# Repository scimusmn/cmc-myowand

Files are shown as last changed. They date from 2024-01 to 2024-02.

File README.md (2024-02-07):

# cmc-myowand

A myoelectric sensor demonstrator, converting muscular electrical impulses into music.

## overview

There are two main subfolders here: `electronics` contains the schematics and board layouts, as well as some information on how they were designed. `code` contains two things:

 * `cinci-biomed-myo`: the Arduino sketch that processes the amplified myoelectric signals and outputs them to the computer over serial
 * `myowand-audio`: the JavaScript code to receive the Arduino's messages and conver them into musical tones.

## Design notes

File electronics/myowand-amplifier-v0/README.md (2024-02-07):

# myowand-amplifier-v0

A prototype version of the MyoWand board. **I CANNOT EMPHASIZE ENOUGH THAT THIS BOARD IS A PROTOTYPE!** It omits several features that should be included in the final design. This board is essentially a pared-down version of the [ModularEEG amplifier board](https://openeeg.sourceforge.net/doc/modeeg/modeeg.html).

The TRS jacks connect to external [Olimex active electrodes](https://www.olimex.com/Products/EEG/Electrodes/EEG-AE/open-source-hardware) which seem to give much better signals than ordinary electrodes, especially without electrolyte solution.

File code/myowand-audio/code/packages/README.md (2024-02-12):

# myowand-audio/code/packages

  * `server`: a NodeJS server that takes serial data from the Arduino and re-transmits it to the browser via websockets.
  * `browser`: a vanilla-js application that both plots incoming websocket data and converts it to sound.

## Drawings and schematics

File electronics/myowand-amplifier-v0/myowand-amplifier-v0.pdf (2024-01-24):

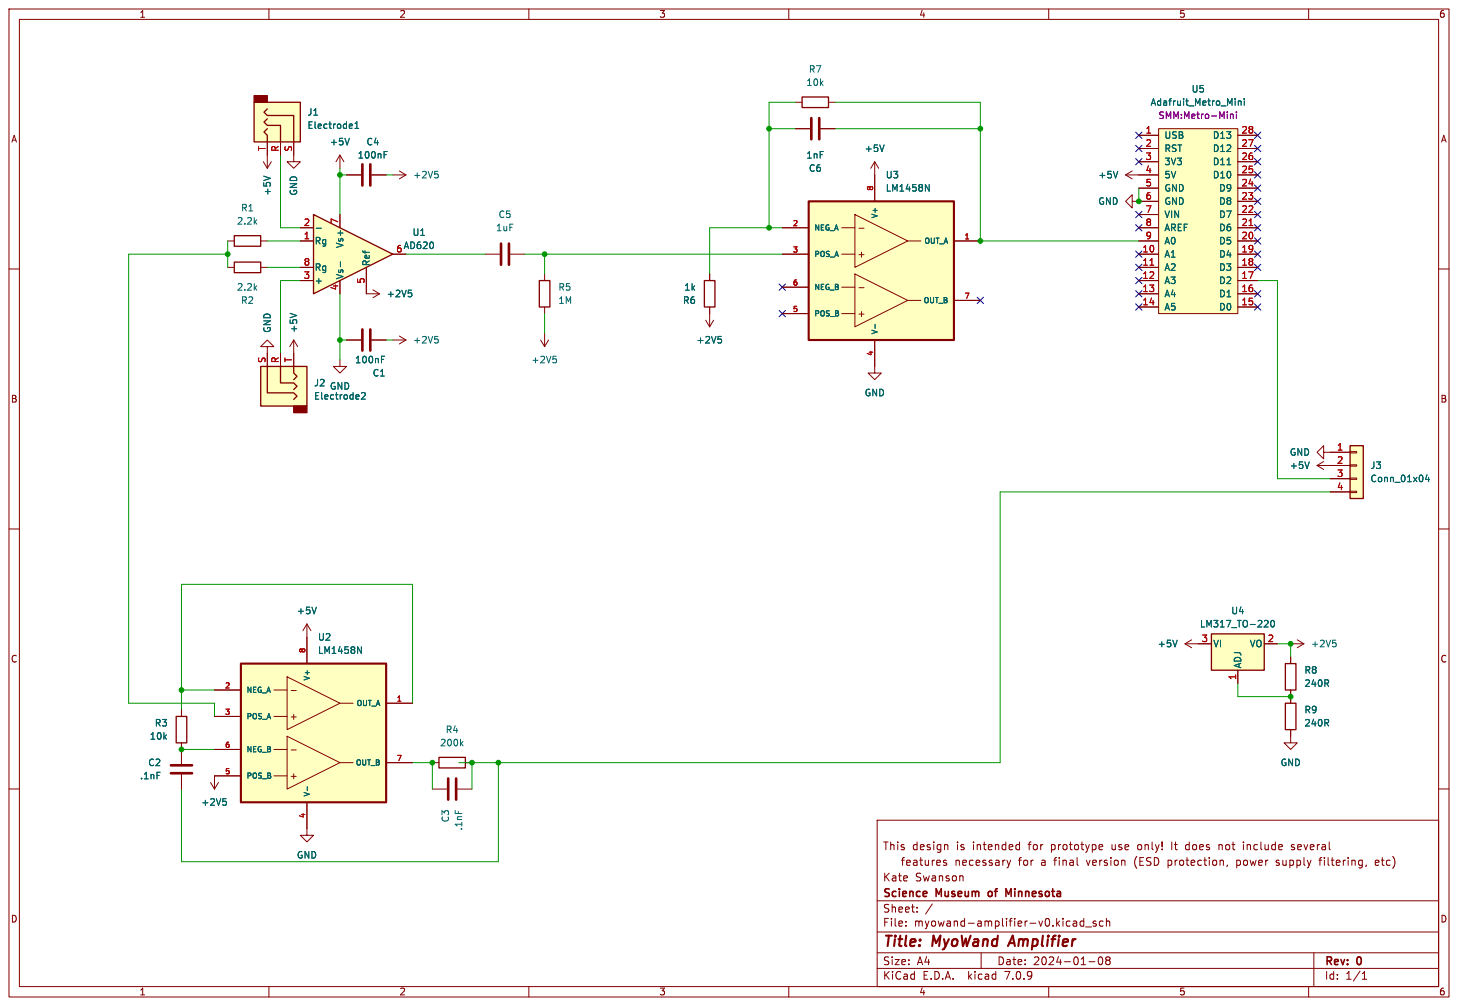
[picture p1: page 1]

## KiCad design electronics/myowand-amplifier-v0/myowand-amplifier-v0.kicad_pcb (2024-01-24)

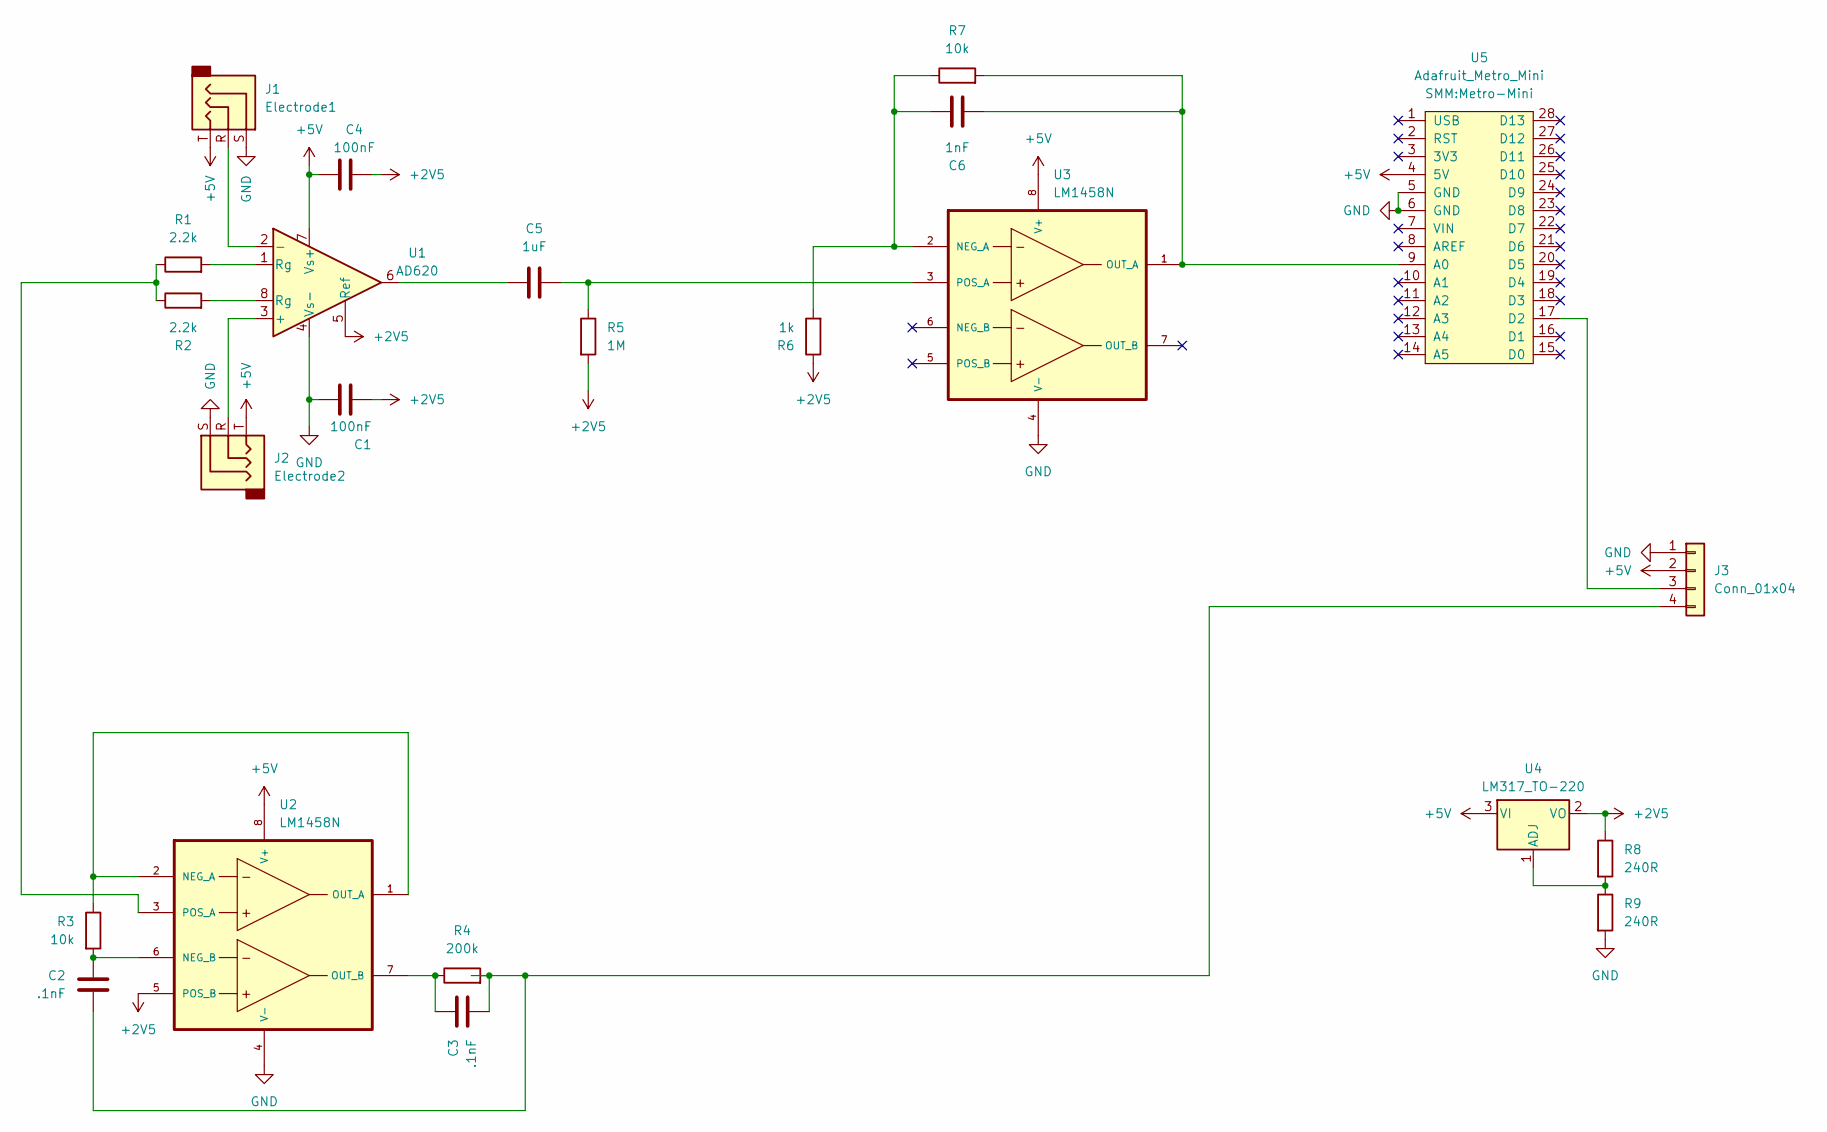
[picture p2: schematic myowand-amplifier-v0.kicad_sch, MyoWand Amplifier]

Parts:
C1, C4: 100nF; C_Disc_D8.0mm_W2.5mm_P5.00mm
C2, C3: .1nF; C_Disc_D8.0mm_W2.5mm_P5.00mm
C5: 1uF; C_Disc_D8.0mm_W2.5mm_P5.00mm
C6: 1nF; C_Disc_D8.0mm_W2.5mm_P5.00mm
J1: Electrode1; Jack_3.5mm_CUI_SJ1-3523N_Horizontal
J2: Electrode2; Jack_3.5mm_CUI_SJ1-3523N_Horizontal
J3: Conn_01x04; KK-1x04
R1, R2: 2.2k; Resistor_L6.3mm_D2.5mm_P10.16mm_Horizontal
R3, R7: 10k; Resistor_L6.3mm_D2.5mm_P10.16mm_Horizontal
R4: 200k; Resistor_L6.3mm_D2.5mm_P10.16mm_Horizontal
R5: 1M; Resistor_L6.3mm_D2.5mm_P10.16mm_Horizontal
R6: 1k; Resistor_L6.3mm_D2.5mm_P10.16mm_Horizontal
R8, R9: 240R; Resistor_L6.3mm_D2.5mm_P10.16mm_Horizontal
U1: AD620; DIP-8_W7.62mm_Socket
U2, U3: LM1458N; DIP-8_W7.62mm_Socket
U4: LM317_TO-220; TO-220-3_Vertical
U5: Adafruit_Metro_Mini; Metro-Mini

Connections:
+2V5: C1.1, C4.2, R5.2, R6.1, R8.1, U1.5 (Ref), U2.5 (POS_B), U4.2 (VO)
+5V: C4.1, J1.T, J2.T, J3.2, U1.7 (Vs+), U2.8 (V+), U3.8 (V+), U4.3 (VI), U5.4 (5V)
GND: C1.2, J1.S, J2.S, J3.1, R9.2, U1.4 (Vs-), U2.4 (V-), U3.4 (V-), U5.5 (GND), U5.6 (GND)
unnamed: C5.1, U1.6
unnamed: J3.3, U5.17 (D2)
unnamed: C2.2, C3.2, J3.4, R4.2
unnamed: R1.2, U1.1 (Rg)
unnamed: R2.2, U1.8 (Rg)
unnamed: J2.R, U1.3 (+)
unnamed: J1.R, U1.2 (-)
unnamed: R3.1, U2.1 (OUT_A), U2.2 (NEG_A)
unnamed: C2.1, R3.2, U2.6 (NEG_B)
unnamed: C3.1, R4.1, U2.7 (OUT_B)
unnamed: R1.1, R2.1, U2.3 (POS_A)
unnamed: C6.1, R6.2, R7.1, U3.2 (NEG_A)
unnamed: C6.2, R7.2, U3.1 (OUT_A), U5.9 (A0)
unnamed: C5.2, R5.1, U3.3 (POS_A)
unnamed: R8.2, R9.1, U4.1 (ADJ)

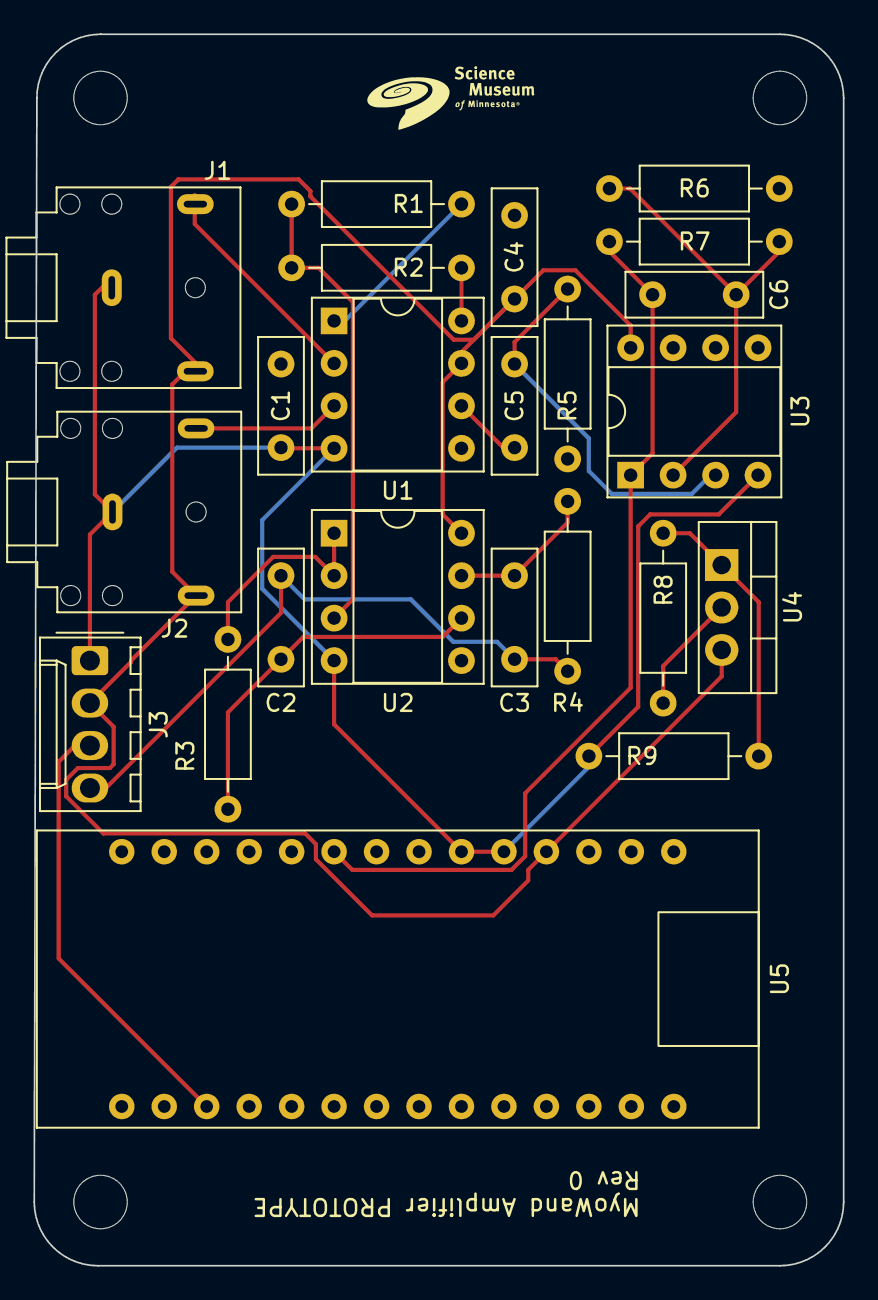
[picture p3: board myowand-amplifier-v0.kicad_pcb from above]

Board: 2 copper layers, 48.4 x 73.7 mm, 23 parts (0 on the bottom side), 18 nets.

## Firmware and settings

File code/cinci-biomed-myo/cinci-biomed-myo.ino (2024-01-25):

#include "signal_proc.h"

#define SIGNAL_PIN A0
#define TOUCH_PIN 2


RollingMin<10> minimum;
RollingMax<10> maximum;
RollingAvg<5> avg;
RollingAvg<50> smoothMax;
RollingAvg<50> smoothMin;
RollingAvg<50> smoothDiff;
RollingAvg<80> music;


struct seg_t {
	double lo, hi;
	int levels;
};
struct seg_t s = { 0, 0.8, 5 };


double clamp(double x, double min, double max) {
  if (x < min) { return min; }
  else if (x > max) { return max; }
  else { return x; }
}

double segment(double value, struct seg_t s) {
	double delta = s.hi - s.lo;
	double a = (value - s.lo) / delta;
	int level = floor(a * s.levels);
	if (level > s.levels) { level = s.levels; }
  else if (level < 0) { level = 0; }
	return ((double)level)/s.levels;
}


void setup() {
  pinMode(TOUCH_PIN, INPUT);
	Serial.begin(115200);
}

void loop() {
	double sig = analogRead(SIGNAL_PIN);
	avg.push(sig);
	double centered = sig - avg.value();
  centered = clamp(centered, -20, 20);
	minimum.push(centered);
	maximum.push(centered);
	smoothMin.push(minimum.value());
	smoothMax.push(maximum.value());
	Serial.print(centered); Serial.print(" ");
	// Serial.print((smoothMin.value())); Serial.print(" ");
	// Serial.print((smoothMax.value())); Serial.print(" ");
	Serial.print(s.levels); Serial.print(" 0 ");
  // Serial.print("2 0 ");
	double diff = smoothMax.value() - smoothMin.value();
  // clamp diff to range [0, 50]
  if (diff < 0) { diff = 0; }
  else if (diff > 50) { diff = 50; }
	// double ldiff = diff < 2.718 ? 0 : log(log(diff));
  double ldiff = clamp(log(diff), 0, 2)/2;
	smoothDiff.push(ldiff);
	music.push(segment(smoothDiff.value(), s));
	Serial.print(5*smoothDiff.value()); Serial.print(" ");
  // music.push( segment(log(sqrt(smoothDiff.value()/2)), s) );
	Serial.print((int) (s.levels * music.value())); Serial.print(" ");
	// Serial.println(ldiff);
  Serial.print(digitalRead(TOUCH_PIN)); Serial.print(" ");
  Serial.println();
  delay(1);
}
